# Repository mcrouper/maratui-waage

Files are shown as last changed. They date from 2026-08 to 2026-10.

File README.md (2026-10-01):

<p align="center">
    MaraTUI — rat barista
    <br><br>
    <a href="https://github.com/ratatui/ratatui">
        
    </a>
</p>

# MaraTUI

An embedded Rust TUI application for the **Lelit Mara X** espresso machine. Runs on an **ESP32** microcontroller driving an **ILI9341 320×240 display** over SPI, reads machine telemetry over UART, and publishes events to MQTT. Includes a host simulator mode for UI development without any hardware.

## Screenshots

| Loading | Dashboard | Debug |
|---|---|---|
| Loading | Dashboard | Debug |

## Screens

Navigation cycles between two main screens with a button press. The Debug screen is a hidden overlay.

### Dashboard

The primary screen. Shows all real-time machine data:

- **Mode banner** — COFFEE / STEAM / OFFLINE, color-coded
- **Boiler gauge** — current vs. target temperature with warm→ready color zones and a target marker
- **HX column** — heat-exchanger temperature with a vertical mini-gauge; ideal zone (90–95°C) is always visible
- **HEAT / PUMP indicators** — live status dots
- **Extraction timer** — large countdown in seconds, color shifts white→green→yellow as the shot progresses
- **Weight** — live shot weight in grams from the dual-HX711 scale, auto-tared the moment the pump starts
- **Shot gauge ("%")** — tracks extracted weight against a 40g target, not elapsed time
- **Shot quality label** — post-extraction assessment (UNDEREXTRACTED / GOOD / PERFECT / LONG SHOT / BLONDING) shown after the pump stops
- **Cup counter** — total shots brewed, received via MQTT

### Graphs

Temperature history chart over a **5-minute rolling window** sampled at 1 Hz:

- Boiler current temperature (yellow)
- Boiler target temperature (red)
- HX temperature (blue)

### Debug (hidden overlay)

Accessible via long press. Shows Wi-Fi and MQTT connection statuses, device info (SSID, RSSI, IP, uptime, free heap), live raw UART frame with activity indicator, and the last 10 telemetry events.

## Getting Started

### Simulator

The simulator runs on your host machine using SDL2 for display emulation — no ESP32 needed.

**Prerequisites:** install SDL2 development libraries for your OS ([installation guide](https://docs.rs/crate/sdl2/latest/source/README.md)).

```bash
make sim          # auto-detects OS
```

Or use platform-specific cargo aliases:

| OS | Command |
|---|---|
| Linux | `cargo sim` |
| macOS | `cargo simmac` |
| Windows | `cargo simwin` |

**Keyboard controls:**

| Key | Action |
|---|---|
| Right / Left | Toggle Dashboard ↔ Graphs |
| D | Toggle Debug overlay |
| Up | Inject pump-on debug frame |
| Down | Inject normal debug frame |
| Space | Inject no-water debug frame |
| M | Publish manual MQTT event |

### Device (ESP32)

**Prerequisites:** Rust with the `esp` toolchain channel (pinned in `rust-toolchain.toml`).

```bash
cargo run --release
```

Uses `espflash flash --monitor` as the runner. On startup the firmware:

1. Connects to Wi-Fi using embedded credentials
2. Starts the MQTT client and subscribes to `<prefix>/cup_counter`
3. Streams telemetry to `<prefix>/telemetry` (~1 Hz)
4. Publishes events (shot start/end, water refill, mode change) to `<prefix>/events`
5. Publishes device status (IP, RSSI, uptime, heap) to `<prefix>/status`

## Configuration

Copy `.env.example` to `.env` (git-ignored) and fill in your values:

```bash
cp .env.example .env
```

| Variable | Description |
|---|---|
| `MARATUI_WIFI_SSID` / `_PASSWORD` | Wi-Fi credentials (device build only) |
| `MARATUI_MQTT_ENABLED` | Set `true` to enable MQTT publishing |
| `MARATUI_MQTT_URL` | Broker URL, e.g. `mqtt://192.168.1.x:1883` |
| `MARATUI_MQTT_CLIENT_ID` | Unique client identifier |
| `MARATUI_MQTT_TOPIC_PREFIX` | Topic namespace prefix (default: `mara`) |

> [!NOTE]
> On the ESP32 build (`device` feature), `.env` is parsed by `build.rs` and values are embedded at compile time. On the simulator (`simulator` feature), env values are read at runtime and Wi-Fi is skipped — host networking is used directly for MQTT.

> [!WARNING]
> Wi-Fi and MQTT credentials are stored as plaintext `&'static str` in the flash image. Rotate credentials if the device is shared or its firmware is distributed. See the [Security Considerations](#security-considerations) section below.

## Home Assistant Integration

Build with `--features home-assistant` to enable MQTT Discovery publishing directly from the firmware — no Node-RED or other bridge required. On every MQTT connect, retained discovery configs are published and entities appear in Home Assistant automatically.

```bash
cargo run --release --features home-assistant   # flash
make sim-ha                                      # simulator
```

See [docs/home-assistant.md](docs/home-assistant.md) for the full entity list, MQTT topic reference, and cup counter setup.

## Web Dashboard

A standalone live dashboard page (temperatures with history, live scale weight, shot timer and weight curve, recent shots, events, device status) served by Node-RED at `http://<node-red-host>:1880/mara`, deployed with `python3 dashboard/deploy.py`. See [dashboard/README.md](dashboard/README.md).

## Hardware

Target board: **ESP32 Type-C** with an external **ILI9341** 240×320 TFT display connected over SPI. There is a single physical button.

| Press | Action |
|---|---|
| Short | Toggle Dashboard ↔ Graphs |
| Short (on loading)| Toggle display backlight |
| Double (fast 2x)  | Zero the scale |
| Long | Enter / exit Debug overlay |
| Hold (3s) | Start the scale calibration wizard |

See [`hardware/`](hardware/) for the KiCad project, PCB renders, Gerber files, and full ESP32 pinout and display wiring.

### Scale (dual HX711 load cells)

Two independent HX711 amplifiers — one per drip-tray side — feed the live Weight display and
the weight-based shot gauge. Hold the button for 3s to run the calibration wizard (tare, then a
known reference weight, for each cell in turn); results persist to NVS. The scale also auto-tares
at boot and at the start of every shot; a fast double press zeroes it manually at any time. See
[`docs/hardware.md`](docs/hardware.md) for wiring and the full calibration walkthrough.

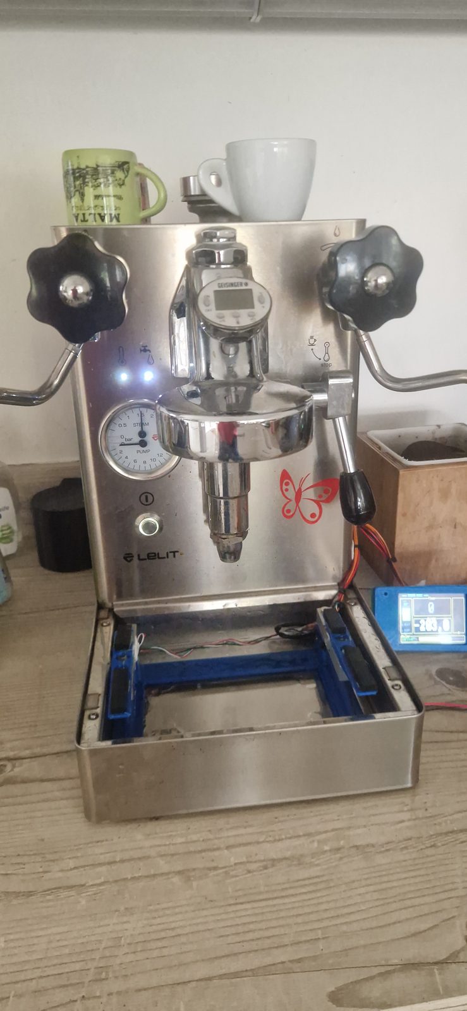
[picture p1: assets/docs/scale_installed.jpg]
Scale installed in the machine
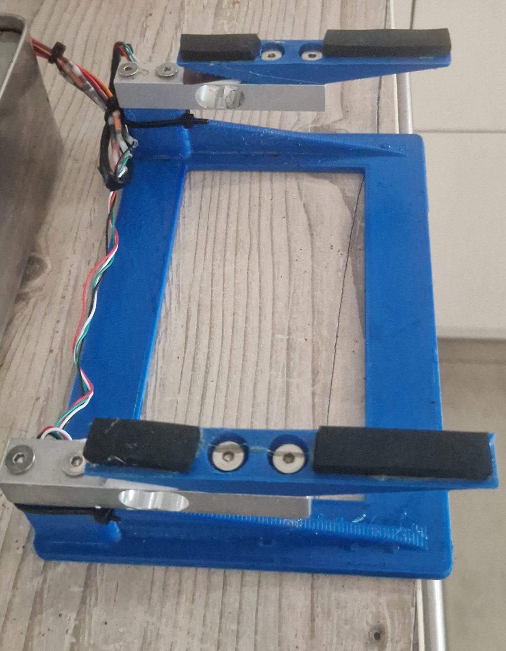
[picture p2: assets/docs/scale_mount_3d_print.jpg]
3D-printed scale mount with both load cells
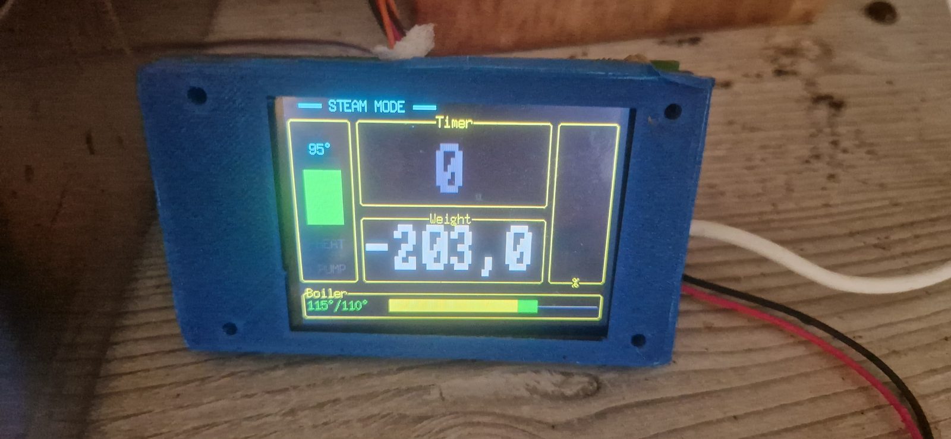
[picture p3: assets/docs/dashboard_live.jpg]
Dashboard showing a live weight reading
|  |  |  |
|:---:|:---:|:---:|

## Security Considerations

- **Credentials in flash** — Wi-Fi and MQTT credentials are embedded at compile time and extractable from the flash image with standard tools (`strings`, `binwalk`). Rotate if the device is shared.
- **Default broker is public** — `mqtt://broker.emqx.io:1883` is a free public broker with no access control. Set a private broker with authentication before deploying.
- **No TLS** — traffic is plaintext TCP. Switch to `mqtts://` and configure a CA certificate for production use.
- **Open Wi-Fi fallback** — if `MARATUI_WIFI_PASSWORD` is empty, `AuthMethod::None` is used (no encryption). A startup `warn!` names the SSID to make this explicit.

## Roadmap

- Offline mode using NVS storage

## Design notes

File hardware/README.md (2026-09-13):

# MaraTUI PCB

Custom ESP32 controller board for the [Lelit Mara X](https://lelitcoffee.com/product/mara-x/) espresso machine.

## PCB Render

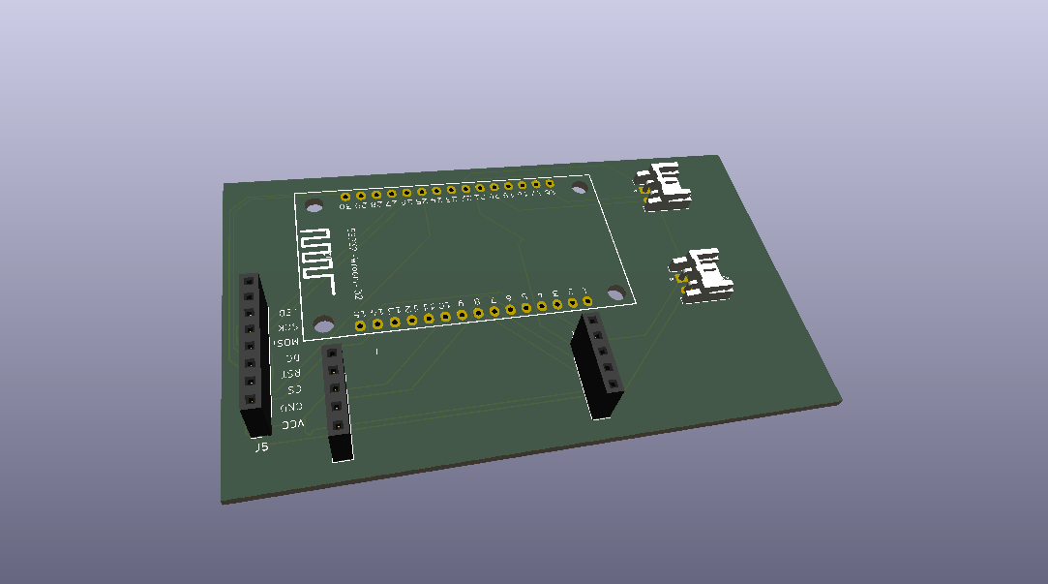
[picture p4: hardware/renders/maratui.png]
PCB render


## Components

| Ref | Part | Link |
|-----|---|---|
| U1 | ILI9341 2.8" SPI TFT with touch | [Amazon TR](https://www.amazon.com.tr/2-8in%C3%A7-SPI-Dokunmatik-Ekran-Mod%C3%BCl%C3%BC/dp/B0GWFFJBZN) |
| U2 | ESP32-WROOM-32 | [Amazon TR](https://www.amazon.com.tr/ESP32-Wroom-32-Wifi-Bluetooth-Geli%C5%9Ftirme-Kart%C4%B1/dp/B0BT7SW1LF) |
| SW1 | Tactile switch | |
| J1 | Barrel jack (power) | |
| J2 | 3-pin connector (GND + UART) | |
| U3, U4 | HX711 load-cell amplifier (one per scale cell) | |

## Wiring

### SPI Display (ILI9341)

| Display Pin | ESP32 GPIO | Notes |
|---|---|---|
| SCK / CLK | GPIO18 | VSPI CLK |
| SDA / MOSI  | GPIO21 | VSPI MOSI |
| DC / RS | GPIO23 | Data/Command select |
| CS | GPIO19 | Chip Select |
| RST / RESET | GPIO22 | Hardware reset |
| LED / BLK | GPIO14 | Backlight (HIGH = on) |
| VCC | 3.3V | |
| GND | GND | |

### UART (Lelit Mara X telemetry)

| Function | ESP32 GPIO | Notes |
|---|---|---|
| TX | GPIO17 | UART1 TX |
| RX | GPIO16 | UART1 RX |

### Scale (dual HX711 load cells)

| HX711 Pin | ESP32 GPIO | Notes |
|---|---|---|
| DOUT (left)  | GPIO25 | Data, left load cell (input on ESP32) |
| SCK (left) | GPIO26 | Clock, left load cell (output from ESP32) |
| DOUT (right) | GPIO32 | Data, right load cell (input on ESP32) |
| SCK (right)  | GPIO27 | Clock, right load cell (output from ESP32) |

Each HX711 has its **own** DOUT and SCK line (not shared) so the two cells can be clocked and
read independently — one under each side of the drip tray. See
[`docs/hardware.md`](../docs/hardware.md) for E+/E-/A+/A- load-cell wiring and the calibration
procedure.

### Button

| Button | ESP32 GPIO | Notes |
|---|---|---|
| SW1 | GPIO12 | Internal pull-up enabled |

Button connects GPIO to **GND** via a tactile switch (active LOW, falling-edge detection).

- Short press (< 500 ms): cycle screens (Dashboard ↔ Graphs)
- Double press (two short presses within 400 ms): zero the scale
- Long press (≥ 500 ms): toggle Debug screen
- Hold (3 s): start the scale calibration wizard

## Custom Libraries

Non-standard components are bundled in `lib/` so the project opens without missing library errors on any machine.

| File | Description |
|---|---|
| `lib/symbols/esp32_30pin.kicad_sym` | ESP32-WROOM-32 symbol |
| `lib/symbols/tft_320x240.kicad_sym` | ILI9341 320×240 symbol |
| `lib/footprints/maratui.pretty/ESP32_30pin.kicad_mod` | ESP32 footprint |
| `lib/footprints/maratui.pretty/TFT-320x240.kicad_mod` | TFT display footprint |

## Manufacturing

Gerber files for fabrication: `gerbers/gerbers.zip` (single board, scale cells included)

## 3D-Printed Parts (`3d-print/`)

Printable case parts for the dual load-cell scale mount:

| File | Description |
|---|---|
| `doppelfuss.stp` / `ImageToStl.com_doppelfuss.stl` | Double foot — mounts both load cells |
| `auflage_v2.stp` / `ImageToStl.com_auflage_v2.stl` | Scale platform/tray (v2) |
| `CCR10S_ImageToStl.com_auflage_v2.gcode` | Pre-sliced G-code for the platform (Creality CR-10S) |

Tested with JLCPCB default 2-layer settings.

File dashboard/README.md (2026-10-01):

# Web dashboard

A standalone live dashboard page for MaraTUI, served by Node-RED at `http://<node-red-host>:1880/mara`:
boiler / HX temperatures with history, heating / pump / water / boost state, live scale weight,
shot timer, shot weight curve, recent shots (duration, yield, flow), event log and device status.
No external dependencies (no CDN, no Dashboard nodes) — it works on an offline LAN.

## How it works

```
mqtt in (mara/#) → function "Zustand + Broadcast" → websocket out /ws/mara  (broadcast to all pages)
websocket in /ws/mara → function "Snapshot an neuen Client" → websocket out  (state for a new page)
http in GET /mara → template (index.html) → http response
http in GET /mara/shot/:ts → function → http response            (the shot's JPEG, linked in the table)
```

Node-RED keeps the state (last hour of temperatures, last 10 shots, last 30 events) in flow
context, so a freshly opened page is populated immediately; the browser never talks to the MQTT
broker itself, so no broker credentials end up in the page.

Shots survive Node-RED restarts and power cuts: the function node writes them to `$HOME/maratui/`
of the Node-RED user (`--data-dir` to change) and reloads them on start:

- `shots.json` — the last 10 shots incl. weight and HX curves (written atomically with fsync)
- `shotdoku.txt` — plain-text archive; every shot pushed out of the last 10 is appended, e.g.
  `2026-09-27 14:39:28  Dauer 11 s  Gewicht 41,9 g  Fluss 3,8 g/s  HX 95-104 °C  (kurz)` plus a
  weight-per-second line

- `shots/JJJJ-MM-TT_HH-MM-SS.jpg` — one chart per shot (weight curve, HX temperature behind it,
  duration / weight / flow in the title), rendered on the Node-RED host by `render_shot.py`
  (needs `python3` with Pillow and the DejaVu fonts, both on Raspberry Pi OS by default). The
  flow installs the script into the data dir on start and renders missing images for saved shots.
- `cups.json` — total cup count, +1 for every shot that enters the shot list (normal shots and
  short pours with >= 5 g, not rinses). Published retained to `mara/cup_counter`, so the ESP32
  display shows it too — this replaces the Home Assistant automation for setups without HA. To set
  a start value: `mosquitto_pub -r -t mara/cup_counter -m 1234` (plus `-h/-u/-P`); the flow adopts it.

Temperature history and events stay in memory only.

`reducer.js` is the single implementation of how MQTT messages update that state. `deploy.py`
injects it both into the Node-RED function node and into the page, so server and browser can't
drift apart.

## Deploy / update

```bash
python3 dashboard/deploy.py                      # default: http://192.168.178.162:1880
python3 dashboard/deploy.py --url http://host:1880 --broker <mqtt-broker config node id>
python3 dashboard/deploy.py --dry-run            # print the generated flow JSON
```

Creates the Node-RED tab **MaraTUI Web** on first run and updates it in place afterwards (stable
node ids); other flows are left untouched. It subscribes through the existing mqtt-broker config
node named `MaraTUI Broker` unless `--broker` is given. Edit the files here and redeploy rather than
editing the generated nodes in the Node-RED editor.

Requires the Node-RED admin API to be reachable without auth (or add auth handling to `deploy.py`).

## Topics used

`mara/telemetry`, `mara/status`, `mara/events` (incl. `weight_g` on `shot_ended`), `mara/scale`,
`mara/cup_counter` — see [docs/home-assistant.md](../docs/home-assistant.md#mqtt-topics-published-by-maratui).
The `mara` prefix is hardcoded in `deploy.py` (`TOPIC`); change it there if
`MARATUI_MQTT_TOPIC_PREFIX` differs.

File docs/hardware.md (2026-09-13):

# Hardware Wiring

Target board: **ESP32 Type-C** (generic) with external **ILI9341** 240x320 TFT display.

| ESP32 Type-C | ILI9341 Display |
|:---:|:---:|
| ESP32 | ILI9341 |

## Complete Pin Mapping

Tested board: **ESP32 DevKitV1** (30-pin WROOM-32 "DOIT DEVKIT V1" layout). The
`D<n>` column is that board's silkscreen label, which is just `GPIO<n>` — use whichever
matches your board.

| ESP32 GPIO | DevKitV1 label | Function | Direction | Notes |
|---|---|---|---|---|
| GPIO12 | D12  | Button 1 | Input | Internal pull-up, active LOW. Boot-strapping pin (sets flash voltage); safe here since the button only pulls it LOW, and the internal pull-up is applied by software after boot, not during strapping. |
| GPIO14 | D14  | Display backlight | Output | HIGH = on |
| GPIO16 | D16 (silkscreen "RX2") | UART1 RX | Input | Lelit Mara X telemetry. "RX2" label is just a UART2 suggestion — used here as plain GPIO for UART1 |
| GPIO17 | D17 (silkscreen "TX2") | UART1 TX | Output | Lelit Mara X telemetry (unused by device, wired for symmetry) |
| GPIO18 | D18  | Display SCK / CLK | Output | VSPI CLK |
| GPIO19 | D19  | Display CS | Output | VSPI Chip Select |
| GPIO21 | D21  | Display SDA / MOSI | Output | VSPI MOSI |
| GPIO22 | D22  | Display RST | Output  | Hardware reset |
| GPIO23 | D23  | Display DC / RS | Output | Data/Command select |
| GPIO25 | D25  | HX711 DOUT (left)  | Input  | Left load cell |
| GPIO26 | D26  | HX711 SCK (left) | Output | Left load cell |
| GPIO27 | D27  | HX711 SCK (right)  | Output | Right load cell |
| GPIO32 | D32  | HX711 DOUT (right) | Input  | Right load cell |

Details for each subsystem below.

## Pinout

### SPI Display (ILI9341)

| Display Pin | ESP32 GPIO | Notes |
|---|---|---|
| SCK / CLK | GPIO18 | VSPI CLK |
| SDA / MOSI  | GPIO21 | VSPI MOSI |
| DC / RS | GPIO23 | Data/Command select |
| CS | GPIO19 | Chip Select |
| RST / RESET | GPIO22 | Hardware reset |
| LED / BLK | GPIO14 | Backlight (driven HIGH = on) |
| VCC | 3.3V | |
| GND | GND | |

### UART (Lelit Mara X telemetry)

| Function | ESP32 GPIO | Notes |
|---|---|---|
| TX | GPIO17 | UART1 TX |
| RX | GPIO16 | UART1 RX |

### Button

| Button | ESP32 GPIO | Notes |
|---|---|---|
| Button 1 | GPIO12 | Internal pull-up enabled |

Button connects GPIO to **GND** through a tactile switch (active LOW, NegEdge detection).
Short press (< 500 ms): toggle Dashboard ↔ Graphs. Two short presses released within 400 ms
of each other count as a double press instead: zero the scale (see below). Because a lone
short press can't be told apart from the first half of a double press until that 400 ms
window has passed without a second press, every short-press action (screen toggle, backlight
wake) fires up to ~400 ms after release, not instantly. Long press (≥ 500 ms, < 3 s): toggle
Debug screen. Hold ≥ 3 s: start the scale calibration wizard (see below).

### Scale (dual HX711 load-cell amplifiers)

The scale uses **two independent HX711 amplifiers**, each wired to its own load cell
(e.g. one under each side of the drip tray) with its own DOUT *and* SCK line — the two
ADCs are clocked separately rather than sharing one clock. Their raw readings are
calibrated independently and summed into the total weight shown on the Dashboard.

| HX711 Pin | ESP32 GPIO | Notes |
|---|---|---|
| DOUT (left)  | GPIO25 | Data, left load cell (input on ESP32) |
| SCK (left) | GPIO26 | Clock, left load cell (output from ESP32) |
| DOUT (right) | GPIO32 | Data, right load cell (input on ESP32) |
| SCK (right)  | GPIO27 | Clock, right load cell (output from ESP32) |
| VCC (both) | 3.3V / 5V  | Per HX711 board spec |
| GND (both) | GND | |

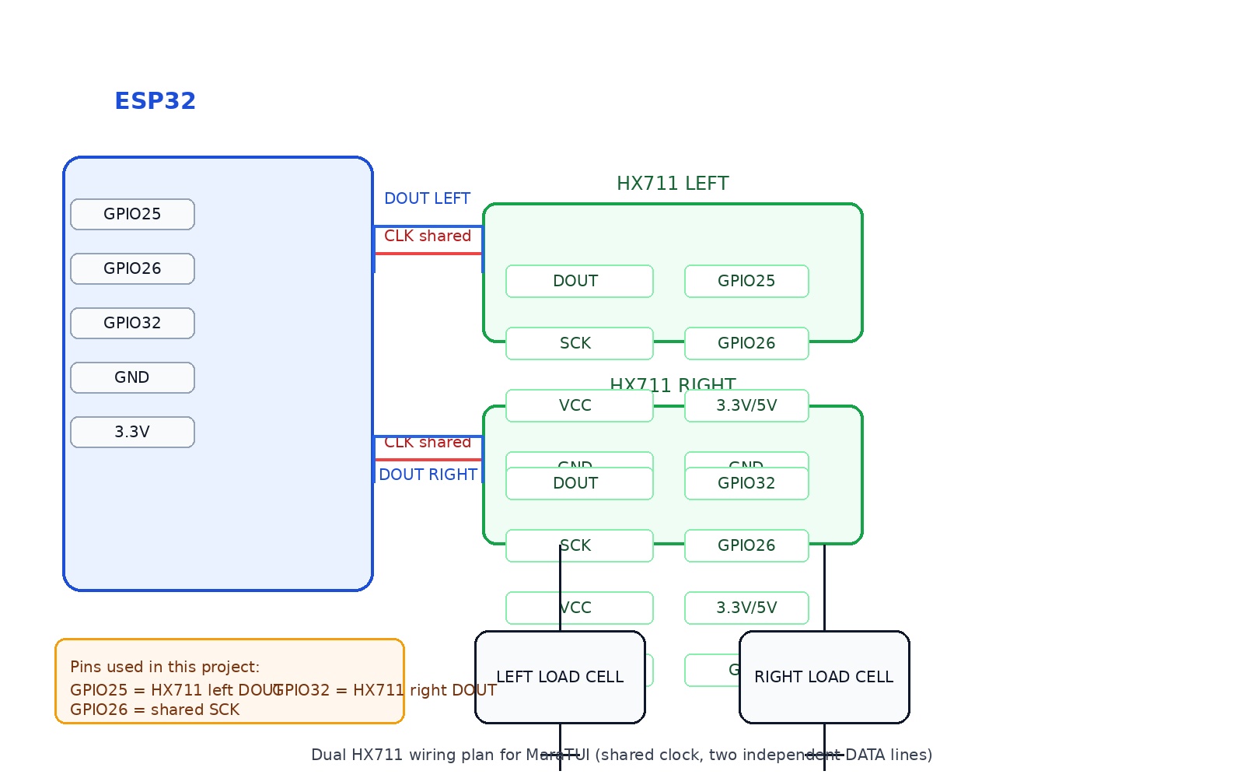
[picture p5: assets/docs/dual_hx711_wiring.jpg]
Dual HX711 wiring
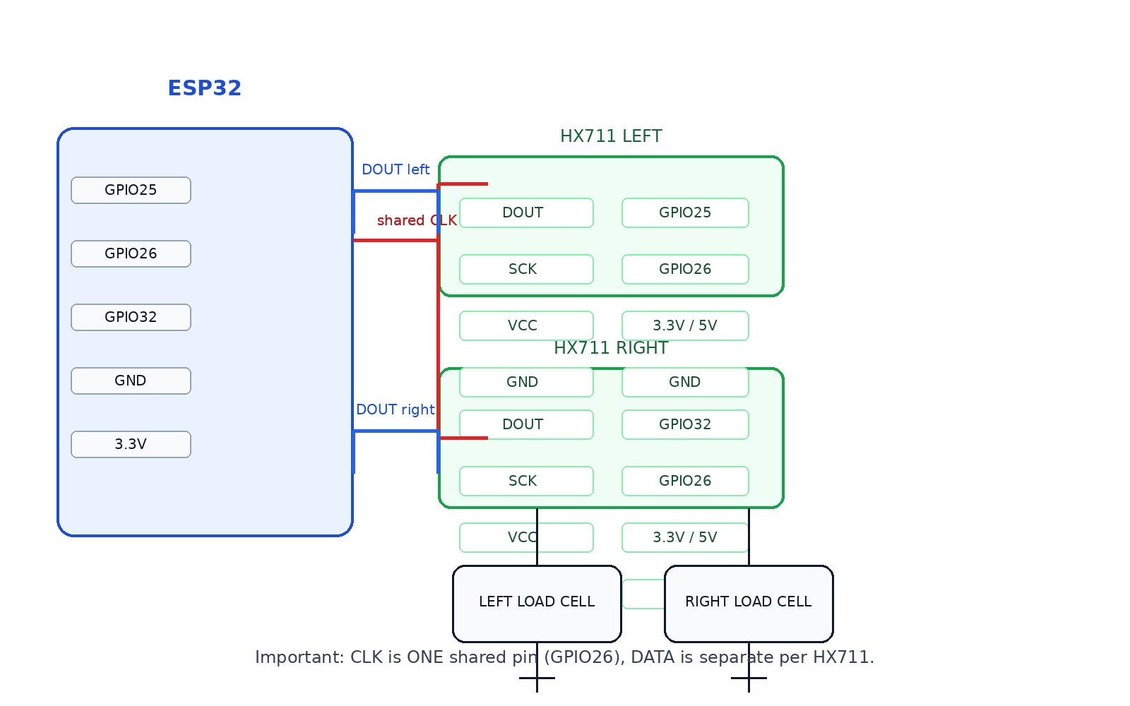
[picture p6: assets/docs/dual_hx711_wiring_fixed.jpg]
Dual HX711 wiring, corrected
|  |  |
|:---:|:---:|

Each load cell connects to its own HX711 board's E+/E-/A+/A- terminals per the load
cell's datasheet. Both drivers read channel A at gain 128 (the HX711 default).

#### Calibrating the scale

Calibration data (per-cell zero-point offset + counts-per-gram factor) is stored in NVS
flash and survives reboots. The wizard calibrates the **left cell first, then the right
cell**, each with its own zero + reference step. To (re-)calibrate:

1. Hold **Button 1** for 3 seconds to enter the calibration wizard.
2. **Left cell — zero point:** remove everything from the scale, then short-press Button 1
   to confirm. The device tares the left HX711 (averages ~10 raw samples as the
   zero-point).
3. **Left cell — reference weight:** place a **500 g** reference weight on the scale, then
   short-press Button 1 to confirm. The device computes the left cell's counts-per-gram
   scale factor from this reading.
4. **Right cell — zero point / reference weight:** repeat steps 2–3 for the right cell.
5. A result screen confirms success for both cells (or reports a read failure — check
   wiring and retry). Press either button to dismiss and return to the previous screen.

A long press at any step during the wizard cancels without changing the stored
calibration. The Dashboard shows live weight (left + right combined) once calibrated; it
auto-tares both cells the moment a shot starts, so it displays the net extracted weight. It
also auto-tares once on the very first reading after boot, and a fast double press zeroes it
manually at any time (ignored while the calibration wizard itself is active).

Before the wizard has ever been run (nothing saved to NVS yet), the scale is uncalibrated
(`ScaleCalibration::default()`, `scale = 0.0`) and readings are rejected outright — the
Dashboard shows `--` until calibration completes.

#### Finished build

The scale mount installed in the Mara X's drip tray, and the Dashboard showing a live weight
reading:

| Scale installed in the machine | 3D-printed scale mount with both load cells | Dashboard showing a live weight reading |
|:---:|:---:|:---:|

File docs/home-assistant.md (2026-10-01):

# Home Assistant Integration

MaraTUI can publish Home Assistant MQTT Discovery configs directly from the firmware — no Node-RED or any other bridge required.

## Architecture

```
ESP32 (MaraTUI)
    │  UART telemetry
    │  MQTT (homeassistant/# discovery + state)
    └─► MQTT broker ──────────────────────────────► Home Assistant
                                                          │
                                                    sensors / binary sensors
                                                    auto-registered via Discovery
```

On connect, the firmware publishes retained discovery configs to `homeassistant/sensor/maratui_*/config` and `homeassistant/binary_sensor/maratui_*/config`. Home Assistant picks them up automatically — no manual YAML needed.

## Prerequisites

- MQTT broker reachable by both the ESP32 and Home Assistant (e.g. Mosquitto on the same host)
- Home Assistant with the MQTT integration enabled (Settings → Devices & Services → MQTT)

## Enabling HA Discovery

Add `--features home-assistant` to your build command:

**Flash to device:**
```bash
cargo run --release --features home-assistant
# or
make flash-ha
```

**Run the simulator:**
```bash
cargo simha          # Linux
cargo simmacHA       # macOS
make sim-ha          # auto-detects OS
```

That's it — on first MQTT connect the firmware publishes all discovery configs, and entities appear in HA within seconds.

## MQTT Topics Published by MaraTUI

### `<prefix>/telemetry` — ~1 Hz JSON frame

```json
{
  "mode": "Coffee",
  "sw": "1.10",
  "boiler_now_c": 93,
  "boiler_target_c": 94,
  "hx_now_c": 91,
  "boost_countdown_s": 0,
  "heating_on": false,
  "pump_on": false,
  "no_water_code": null
}
```

### `<prefix>/events` — on-change JSON events

| `type` | Extra fields | Description |
|---|---|---|
| `shot_started` | — | Pump just turned on |
| `shot_ended` | `duration` (int, seconds), `weight_g` (number or `null`) | Pump turned off; duration and yield (net scale weight, tared at shot start; `null` without a scale reading) |
| `shot_aborted` | `duration` (int, seconds), `weight_g` (number or `null`) | Pump ran < 15 s (rinse / pre-heat kick, or a very short pour) |
| `water_refill_needed` | `code` (int) | Water low detected |
| `water_refill_cleared` | — | Water low cleared |
| `mode_changed` | `from`, `to` (strings) | Machine mode transition |

### `<prefix>/scale` — scale weight, on change (≤ 4 Hz)

```json
{ "weight_g": 36.2 }
```

Net weight shown on the display (grams, one decimal): tared on boot, at every shot start and on a
double press. Published only when the value changes, at most every 250 ms.

### `<prefix>/status` — periodic device info (~30 s)

```json
{
  "uptime_s": 3600,
  "wifi_ssid": "MyNetwork",
  "wifi_rssi": -62,
  "ip": "192.168.1.42",
  "free_heap_b": 180000,
  "last_telemetry_age_s": 1
}
```

The topic prefix defaults to `mara` and is configured via `MARATUI_MQTT_TOPIC_PREFIX` in `.env`.

## Home Assistant Entities

All entities appear under a single device named **Lelit Mara X**.

### Sensors

| Entity | Unit | Notes |
|---|---|---|
| Mode | — | Operating mode |
| Firmware Version | — | Diagnostic |
| Boiler Temperature | °C | `device_class: temperature` |
| Boiler Target | °C | `device_class: temperature` |
| HX Temperature | °C | `device_class: temperature` |
| Last Extraction Duration | s | Retained; updated on shot end |
| Extraction Timer | s | Live counter during shot |
| Time Since Last Shot | min | Minutes since pump last stopped |
| Cup Counter | — | See cup counter setup below |
| Uptime | min | Diagnostic |
| Wi-Fi RSSI | dBm | Diagnostic |
| Wi-Fi SSID | — | Diagnostic |
| IP Address | — | Diagnostic |
| Free Heap | kB | Diagnostic |
| Telemetry Age | s | Diagnostic |

### Binary Sensors

| Entity | Notes |
|---|---|
| Heating | `device_class: heat` |
| Pump Active | On while shot is in progress |
| Water Level Low | `device_class: problem` |

## Cup Counter Setup

The cup counter requires a short one-time setup in Home Assistant. The counter value is stored as an HA helper and published back to the broker so the MaraTUI display stays in sync.

### 1. Create a Counter helper

Settings → Devices & Services → Helpers → **+ Create helper** → **Counter**

- Name: `Mara Shots`
- Entity ID: `counter.coffee_counter` (default)
- Initial value: your current count (or 0)

### 2. Import the automation

Settings → Automations → **+ Create automation** → ⋮ menu → **Edit in YAML**

Paste the contents of `docs/ha-automation.yaml`, save, and enable.

The automation triggers on `mara/events` when `type == shot_ended` and `duration > 20 s`, increments the helper, and publishes the new value to `mara/cup_counter` (retained) so both the HA sensor and the ESP32 display update.

### Cup counter flow

```
MaraTUI → mara/events {"type":"shot_ended","duration":35}
               ↓
         HA automation (ha-automation.yaml)
         duration > 20 s → counter.increment(counter.coffee_counter)
                         → mqtt.publish(mara/cup_counter, retained)
               ↓
         ESP32 subscribes to mara/cup_counter → display updates
         HA sensor maratui_cup_counter reads mara/cup_counter → HA updates
```

## Troubleshooting

**Entities don't appear in HA**
- Check that the MQTT integration is enabled (Settings → Devices & Services → MQTT).
- Confirm the broker MaraTUI connects to is the same one HA uses.
- Subscribe to `homeassistant/#` with `mosquitto_sub -t 'homeassistant/#' -v` to verify discovery configs are arriving.
- Power-cycle or reconnect the ESP32 — discovery configs are re-sent on every MQTT connect.

**Values don't update**
- Confirm the ESP32 is connected to Wi-Fi and MQTT (`MARATUI_MQTT_ENABLED=true` in `.env`).
- Check the MaraTUI Debug screen for UART activity and connection status.
- Subscribe to `mara/#` to see raw messages from the device.

**Topic mismatch**
- If you set `MARATUI_MQTT_TOPIC_PREFIX` to something other than `mara`, update the topics in `docs/ha-automation.yaml` accordingly.

**Cup counter not incrementing**
- Verify the automation is enabled and the trigger topic matches your prefix.
- Check HA automation traces (Settings → Automations → Mara Shot Counter → ⋮ → Traces).

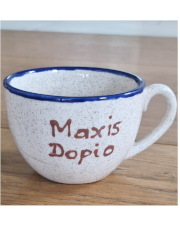
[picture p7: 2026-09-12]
assets/rat_barista.png

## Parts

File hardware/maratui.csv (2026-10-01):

ID | Bezeichner | Footprint | Stückzahl | Bezeichnung | Anbieter und Referenz
1 | J2 | JST_EH_B2B-EH-A_1x02_P2.50mm_Vertical | 1 | Button
2 | J4 | JST_EH_B2B-EH-A_1x02_P2.50mm_Vertical | 1 | Mara
3 | U1 | ESP32_30pin | 1 | ~
4 | U2, U3 | HX711_module | 2 | HX711
5 | U4 | TFT-320x240 | 1 | TFT_320x240

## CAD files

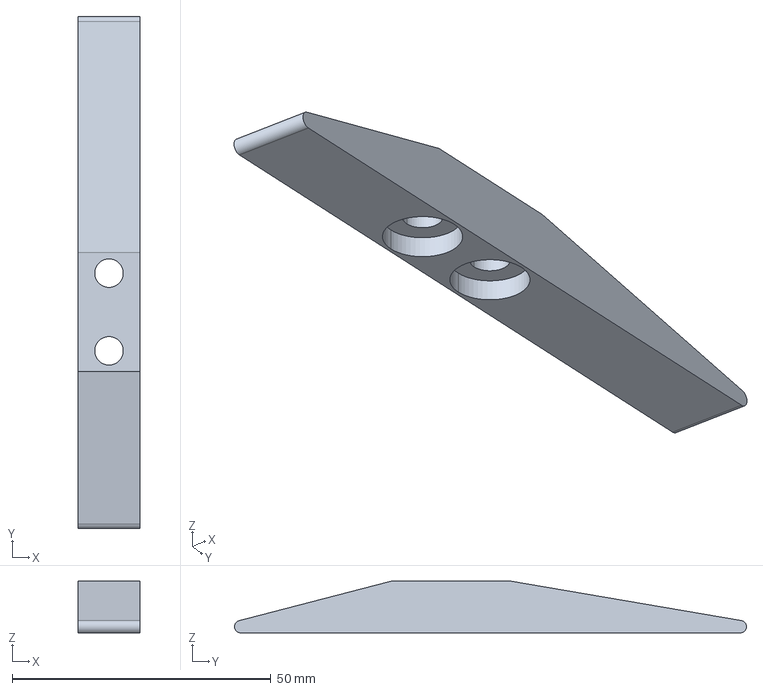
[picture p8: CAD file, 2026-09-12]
hardware/3d-print/auflage_v2.stp
12.0 x 98.9 x 10.0 mm

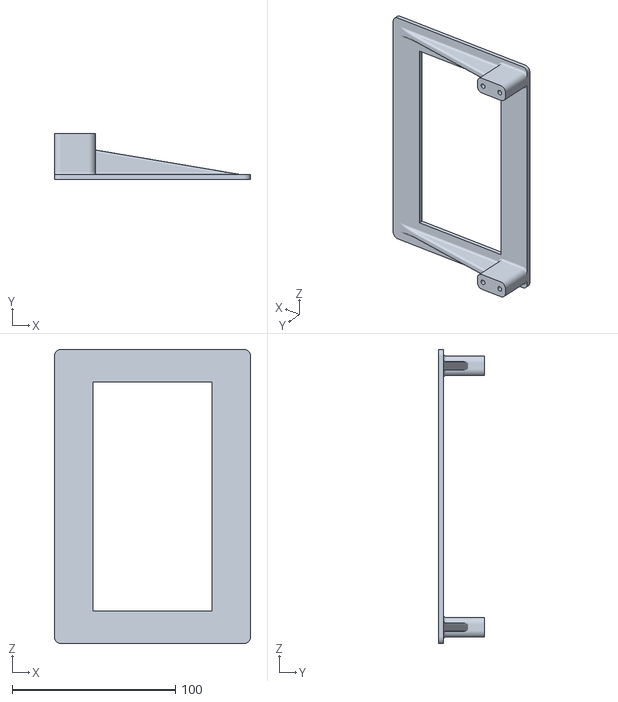
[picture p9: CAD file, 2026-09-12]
hardware/3d-print/ImageToStl.com_doppelfuss.stl
120.0 x 28.0 x 180.0

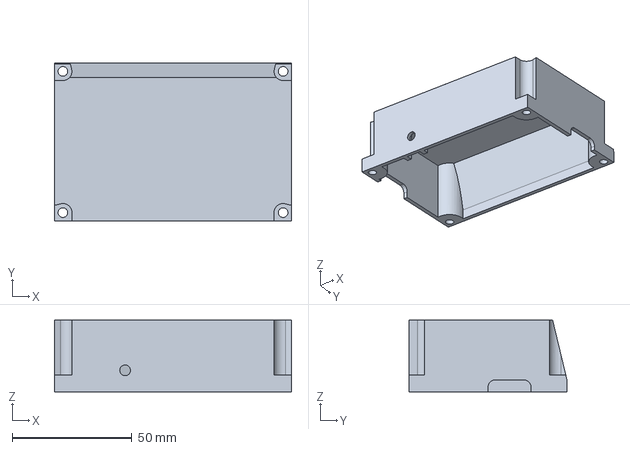
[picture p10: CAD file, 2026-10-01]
hardware/3d-print/00000000000_-_geh_koerper.stp
99.0 x 66.0 x 30.0 mm

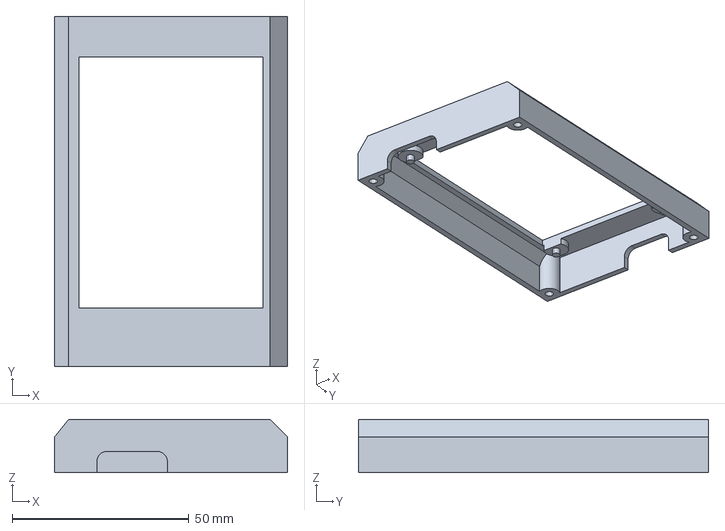
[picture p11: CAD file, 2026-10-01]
hardware/3d-print/00000000000_-_geh_deckel.stp
66.0 x 99.0 x 15.0 mm

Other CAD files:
hardware/3d-print/ImageToStl.com_auflage_v2.stl
hardware/3d-print/doppelfuss.stp

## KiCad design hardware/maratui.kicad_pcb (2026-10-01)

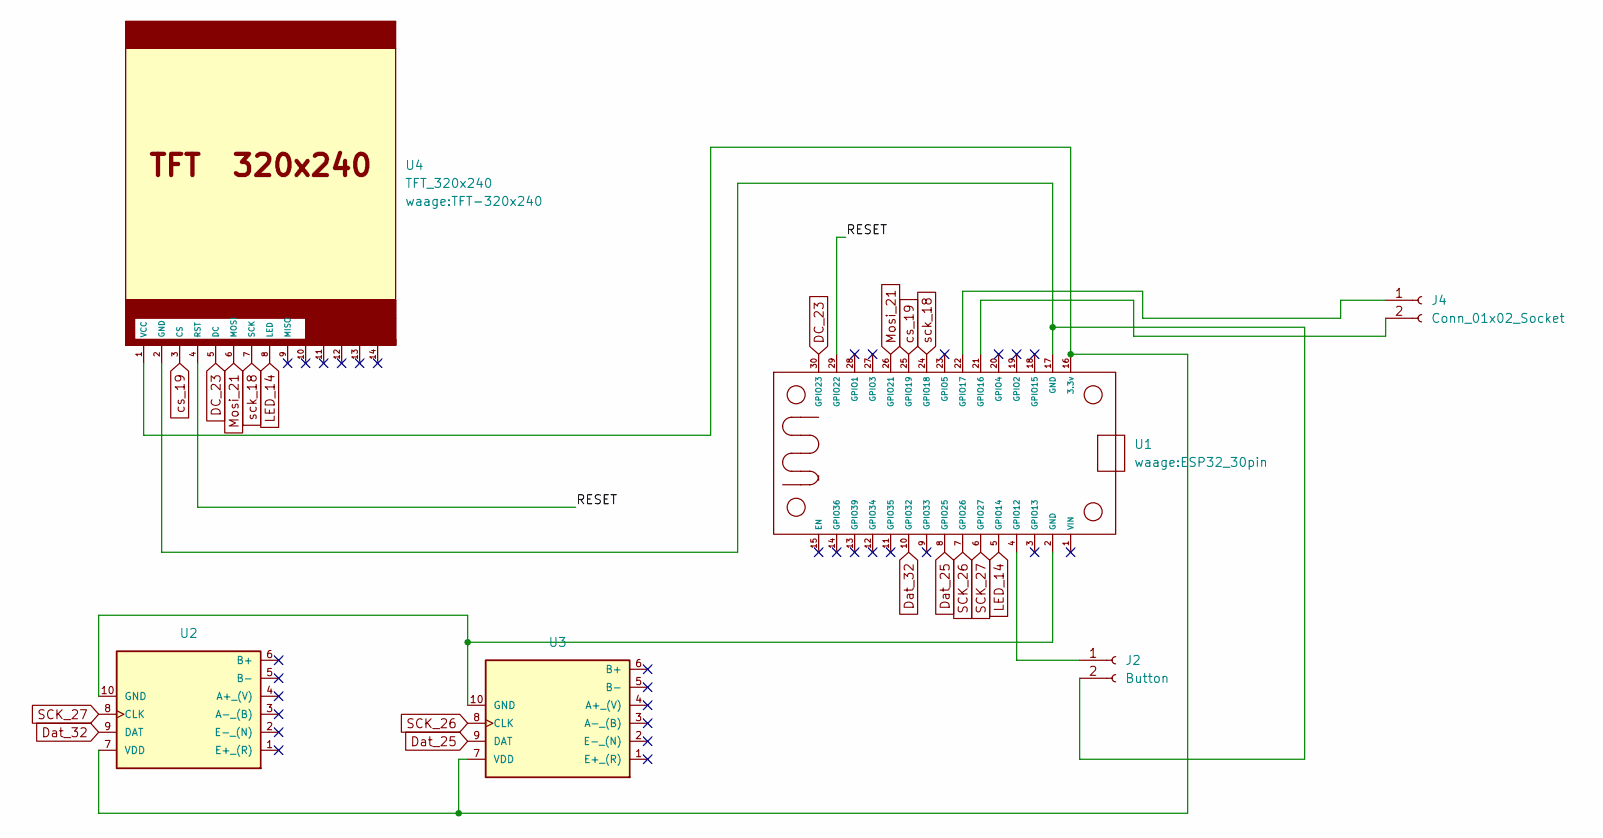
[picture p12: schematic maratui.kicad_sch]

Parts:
J2: Button; JST_EH_B2B-EH-A_1x02_P2.50mm_Vertical
J4: Conn_01x02_Socket; JST_EH_B2B-EH-A_1x02_P2.50mm_Vertical
U1: ESP32_30pin
U2, U3: HX711; HX711_module
U4: TFT_320x240; TFT-320x240

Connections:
/RESET: U1.29 (GPIO22), U4.4 (RST)
DC_23: U1.30 (GPIO23), U4.5 (DC)
Dat_25: U1.8 (GPIO25), U3.9 (DAT)
Dat_32: U1.10 (GPIO32), U2.9 (DAT)
LED_14: U1.5 (GPIO14), U4.8 (LED)
Mosi_21: U1.26 (GPIO21), U4.6 (MOSI)
unnamed: J2.1, U1.4 (GPIO12)
unnamed: J2.2, U1.17 (GND), U4.2 (GND)
unnamed: J4.1, U1.22 (GPIO17)
unnamed: J4.2, U1.21 (GPIO16)
unnamed: U1.16 (3.3v), U2.7 (VDD), U3.7 (VDD), U4.1 (VCC)
unnamed: U1.2 (GND), U2.10 (GND), U3.10 (GND)
SCK_26: U1.7 (GPIO26), U3.8 (CLK)
SCK_27: U1.6 (GPIO27), U2.8 (CLK)
cs_19: U1.25 (GPIO19), U4.3 (CS)
sck_18: U1.24 (GPIO18), U4.7 (SCK)

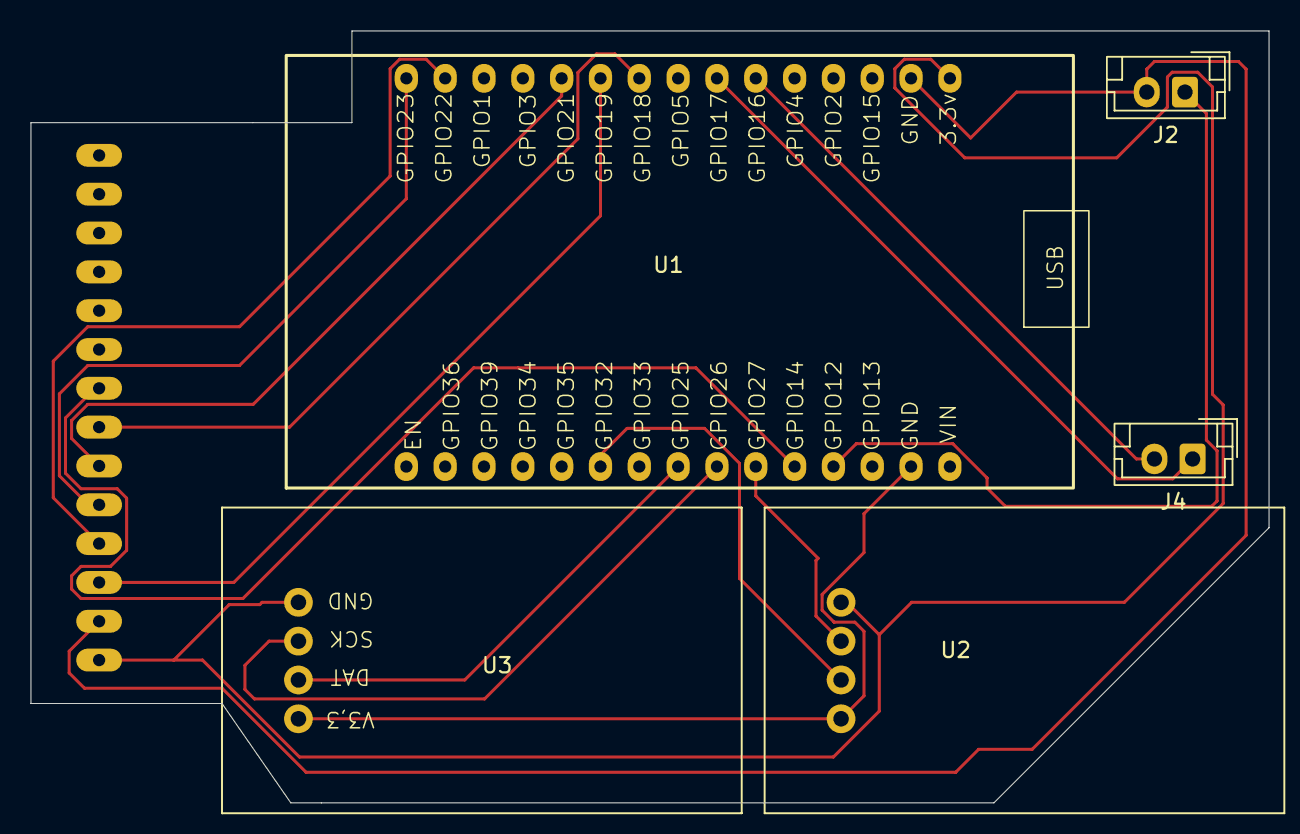
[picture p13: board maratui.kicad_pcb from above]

Board: 2 copper layers, 81.0 x 50.5 mm, 6 parts (1 on the bottom side), 16 nets.

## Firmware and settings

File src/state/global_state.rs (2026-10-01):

use crate::screens::Screen;
use crate::telemetry::MachineState;
use std::{
    collections::VecDeque,
    time::{Duration, Instant},
};

// TODO: if the device is powered directly from the espresso machine, the backlight
// timeout is unnecessary — consider removing BACKLIGHT_TIMEOUT and backlight_should_be_on entirely.
pub const BACKLIGHT_TIMEOUT: Duration = Duration::from_secs(10);

/// How long telemetry may be absent before the machine is considered offline.
///
/// Once this elapses with no UART frame, the UI falls back to the waiting screen and
/// the next frame to arrive starts a fresh session (terminal + graph buffers cleared).
pub const MACHINE_OFFLINE_TIMEOUT: Duration = Duration::from_secs(30);

#[derive(Clone, Debug, Default, PartialEq, Eq)]
pub enum ConnectionStatus {
    Disabled,
    #[default]
    Disconnected,
    Connecting,
    Connected,
    Error(String),
}

#[derive(Clone, Debug)]
pub struct MqttOutboundMessage {
    /// Topic suffix (combined with prefix by publish_mqtt_message) unless `absolute` is true.
    pub topic_suffix: String,
    pub payload: String,
    /// When `true`, the broker should store a retained copy of this message.
    pub retain: bool,
    /// When `true`, `topic_suffix` is used as-is (bypasses prefix construction).
    pub absolute: bool,
}

/// State of the coffee extraction process
#[derive(Clone, Debug, PartialEq, Eq)]
pub enum ExtractionState {
    /// Pump is not running, no extraction in progress
    Idle {
        /// Duration of the last completed extraction
        last_extraction_duration: Option<Duration>,
    },
    /// Pump is running, extraction in progress
    Extracting { started_at: Instant },
}

impl Default for ExtractionState {
    fn default() -> Self {
        Self::Idle {
            last_extraction_duration: None,
        }
    }
}

impl ExtractionState {
    /// Get the duration of the current extraction (if in progress)
    pub fn elapsed(&self) -> Option<Duration> {
        match self {
            ExtractionState::Extracting { started_at } => Some(started_at.elapsed()),
            ExtractionState::Idle { .. } => None,
        }
    }

    /// Check if extraction is currently in progress
    pub fn is_extracting(&self) -> bool {
        matches!(self, ExtractionState::Extracting { .. })
    }

    /// Get the duration of the last completed extraction
    pub fn last_extraction_duration(&self) -> Option<Duration> {
        match self {
            ExtractionState::Idle {
                last_extraction_duration,
            } => *last_extraction_duration,
            ExtractionState::Extracting { .. } => None,
        }
    }
}

/// Board metadata published to MQTT and shown on the Debug screen
#[derive(Clone, Debug, Default, PartialEq, Eq)]
pub struct DeviceInfo {
    pub wifi_ssid: String,
    pub wifi_rssi: Option<i32>,
    pub ip: Option<String>,
    pub uptime_s: u64,
    pub free_heap_b: Option<u32>,
    /// Seconds since the last UART telemetry frame was received
    pub last_telemetry_age_s: Option<u64>,
}

/// Step of the on-screen HX711 scale calibration wizard, started by holding Button1 for 3s.
#[derive(Clone, Copy, Debug, PartialEq, Eq)]
pub enum CalibrationStep {
    /// Ask the user to empty the left scale; a short press confirms and starts taring.
    ConfirmEmptyLeft,
    /// Averaging raw samples for the left scale zero-point.
    TaringLeft,
    /// Ask the user to place the reference weight on the left scale.
    ConfirmReferenceLeft,
    /// Averaging raw samples with the left scale reference weight.
    CalibratingLeft,
    /// Ask the user to empty the right scale; a short press confirms and starts taring.
    ConfirmEmptyRight,
    /// Averaging raw samples for the right scale zero-point.
    TaringRight,
    /// Ask the user to place the reference weight on the right scale.
    ConfirmReferenceRight,
    /// Averaging raw samples with the right scale reference weight.
    CalibratingRight,
    /// Final result, shown briefly before returning to the previous screen.
    Done { success: bool },
}

/// Application errors
#[derive(Clone, Debug, PartialEq, Eq)]
pub enum AppError {
    /// Water refill is needed
    WaterRefillNeeded { code: u16 },
    /// Machine is offline
    MachineOffline,
}

impl std::fmt::Display for AppError {
    fn fmt(&self, f: &mut std::fmt::Formatter<'_>) -> std::fmt::Result {
        match self {
            AppError::WaterRefillNeeded { code } => {
                write!(f, "Water refill needed (code: {})", code)
            }
            AppError::MachineOffline => write!(f, "Machine is offline"),
        }
    }
}
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

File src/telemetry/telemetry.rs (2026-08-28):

// src/telemetry.rs
use std::{collections::VecDeque, time::Instant};
use strum::Display;

#[derive(Debug, Display, Default, Clone, Copy, PartialEq, Eq)]
pub enum MachineMode {
    #[strum(to_string = "Coffee")]
    Coffee, // '-' | '+'
    #[strum(to_string = "Steam")]
    SteamS, // 'S'
    #[strum(to_string = "Steam")]
    SteamV, // 'V'
    #[strum(to_string = "Steam")]
    SteamC, // 'C' (as you described)
    #[default]
    Offline, // 'X'
    Unknown(char),
}

impl MachineMode {
    pub fn from_char(c: char) -> Self {
        match c {
            '-' | '+' => MachineMode::Coffee,
            'S' => MachineMode::SteamS,
            'V' => MachineMode::SteamV,
            'C' => MachineMode::SteamC,
            'X' => MachineMode::Offline,
            other => MachineMode::Unknown(other),
        }
    }
}

#[derive(Debug, Default, Clone, PartialEq, Eq)]
pub struct TelemetryFrame {
    pub raw_string: String,
    pub mode: MachineMode,
    pub sw_version: String,           // e.g. "1.10"
    pub boiler_now_c: u16,            // e.g. 37
    pub boiler_target_c: Option<u16>, // Some(138) or None if Lxx
    pub no_water_code: Option<u16>,   // Some(65) if "L65"
    pub hx_now_c: u16,                // e.g. 35
    pub boost_countdown_s: u16,       // e.g. 0000 -> 0
    pub heating_on: bool,             // "1"/"0"
    pub pump_on: bool,                // "1"/"0"
}

impl TelemetryFrame {
    pub fn offline_frame() -> Self {
        Self {
            raw_string: "offline".to_string(),
            mode: MachineMode::Offline,
            ..Self::default()
        }
    }

    pub fn debug_frame() -> Self {
        Self {
            raw_string: "C1.10,122,128,092,0000,1,0".to_string(),
            mode: MachineMode::SteamC,
            sw_version: "1.10".to_string(),
            boiler_now_c: 122,
            boiler_target_c: Some(128),
            hx_now_c: 92,
            boost_countdown_s: 0,
            heating_on: true,
            pump_on: false,
            no_water_code: None,
        }
    }

    pub fn debug_pump_on_frame() -> Self {
        Self {
            raw_string: "C1.10,120,138,090,0000,1,1".to_string(),
            mode: MachineMode::SteamC,
            sw_version: "1.10".to_string(),
            boiler_now_c: 120,
            boiler_target_c: Some(138),
            hx_now_c: 90,
            boost_countdown_s: 0,
            heating_on: true,
            pump_on: true,
            no_water_code: None,
        }
    }

    pub fn debug_no_water_frame() -> Self {
        Self {
            raw_string: "C1.10,122,L65,085,0000,0,0".to_string(),
            mode: MachineMode::Coffee,
            sw_version: "1.10".to_string(),
            boiler_now_c: 122,
            boiler_target_c: None,
            hx_now_c: 85,
            boost_countdown_s: 0,
            heating_on: false,
            pump_on: false,
            no_water_code: Some(65),
        }
    }
}

#[derive(Debug, Clone, PartialEq, Eq)]
pub enum ParseError {
    Empty,
    BadPrefix,
    WrongFieldCount { got: usize, expected: usize },
    BadNumber { field: &'static str, value: String },
    BadBool { field: &'static str, value: String },
}

/// Parses UART line format:
/// <Mode><Version>,<boiler_now>,<boiler_target_or_Lxx>,<hx_now>,<boost>,<heating>,<pump>
/// Examples:
/// - C1.10,037,138,035,0000,0,1
/// - C1.10,037,L65,035,0000,0,0   (no water)
/// - +1.10,089,P75,067,0000,0,0   (P-prefix seen at cold startup in xmode_coffee; semantics TBD)
pub fn parse_uart_line(line: &str) -> Result<TelemetryFrame, ParseError> {
    let s = line.trim();
    if s.is_empty() {
        return Err(ParseError::Empty);
    }

    // First char is the machine mode
    let mut chars = s.chars();
    let mode_char = chars.next().ok_or(ParseError::Empty)?;
    let mode = MachineMode::from_char(mode_char);

    // Until the first comma is a software version (e.g. "1.10")
    let rest = &s[mode_char.len_utf8()..];
    let comma_pos = rest.find(',').ok_or(ParseError::BadPrefix)?;
    let sw_version = rest[..comma_pos].to_string();

    let after = &rest[comma_pos + 1..];
    let parts: Vec<&str> = after.split(',').collect();

    // Expected 6 fields after version:
    // boiler_now, boiler_target_or_Lxx, hx_now, boost, heating, pump
    if parts.len() != 6 {
        return Err(ParseError::WrongFieldCount {
            got: parts.len(),
            expected: 6,
        });
    }

    let boiler_now_c = parse_u16(parts[0], "boiler_now_c")?;

    let (boiler_target_c, no_water_code) = {
        let t = parts[1].trim();
        if let Some(code) = t.strip_prefix('L') {
            let code = parse_u16(code, "no_water_code")?;
            (None, Some(code))
        } else if t.starts_with(|c: char| c.is_ascii_alphabetic()) {
            // Non-numeric prefix other than 'L' — observed as "Pxx" at cold startup in xmode_coffee.
            // Exact semantics are still under investigation (possibly power-up / initial-heating phase).
            // Accepted without error; boiler_target treated as unknown until the frame normalises.
            (None, None)
        } else {
            let target = parse_u16(t, "boiler_target_c")?;
            (Some(target), None)
        }
    };

    let hx_now_c = parse_u16(parts[2], "hx_now_c")?;
    let boost_countdown_s = parse_u16(parts[3], "boost_countdown_s")?;
    let heating_on = parse_bool01(parts[4], "heating_on")?;
    let pump_on = parse_bool01(parts[5], "pump_on")?;

    let raw_string = line.to_string();

    Ok(TelemetryFrame {
        raw_string,
        mode,
        sw_version,
        boiler_now_c,
        boiler_target_c,
        no_water_code,
        hx_now_c,
        boost_countdown_s,
        heating_on,
        pump_on,
    })
}

fn parse_u16(s: &str, field: &'static str) -> Result<u16, ParseError> {
    let t = s.trim();
    t.parse::<u16>().map_err(|_| ParseError::BadNumber {
        field,
        value: t.to_string(),
    })
}

fn parse_bool01(s: &str, field: &'static str) -> Result<bool, ParseError> {
    match s.trim() {
        "0" => Ok(false),
        "1" => Ok(true),
        other => Err(ParseError::BadBool {
            field,
            value: other.to_string(),
        }),
    }
}

const MIN_SHOT_SECS: u64 = 15;
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

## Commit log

2026-08-28 feat(scale): add dual-HX711 load-cell scale with calibration wizard
    Adds hardware-agnostic calibration math + NVS persistence (scale.rs),
    a bit-banged HX711 driver (hx711.rs), a CalibrationWizard screen
    triggered by holding Button1 for 3s, and a live weight readout on the
    Dashboard that auto-tares the moment a shot starts.
    Claude-Session: https://claude.ai/code/session_011yGqamJeWCJ1JAwKL9S712
2026-08-28 feat(scale): independent SCK pins per HX711, hardware docs, and a scale-test bring-up variant
    - hx711.rs/setup.rs: each HX711 now gets its own SCK line (left: GPIO26,
    right: GPIO27) instead of sharing one clock pin.
    - docs/hardware.md: document the corrected dual-HX711 wiring, add a
    DevKitV1 D<n> silkscreen column, and a complete pin-mapping table.
    - New optional `scale-test` cargo feature for hardware bring-up with
    only the display + scale wired (no Lelit Mara UART connection): shows
    raw, uncalibrated, EMA-smoothed left/right/sum ADC counts in the
    Weight field instead of the normal calibrated net weight.
    - scale.rs: adds RawSignalSmoother (exponential moving average) used by
    the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
    [fsm.rs, global_state.rs, hx711.rs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]
2026-09-12 feat(dashboard,scale): boot text, gauge-by-weight, and scale reading fixes
    Dashboard/connecting screen:
    - Timer/Weight stack: swap centered_half_height for centered_fixed_height
    so the BigText glyph gets its full needed rows instead of being clipped
    by a second, redundant halving on top of the vertical Timer/Weight split
    - Weight gains a decimal (German comma, not period — the period glyph is
    too small to render at this size) and a 2px upward nudge
    - Shot gauge ("%") now tracks extracted weight (40g = 100%) instead of
    elapsed time
    - Boot screen title: "MARA/TUI" -> "MAXI/TUI"
    - Regenerated rat_barista.png/.raw from a new source photo (handle visible)
    Scale (src/scale.rs, src/setup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
    [scale.rs, setup.rs]
2026-09-12 docs: correct stale scale/button/asset documentation
    - CLAUDE.md: Screens section described a nonexistent Button2 and a "Main"
    screen in the rotation — the crate has one physical button and a
    three-variant Screen enum (Dashboard/Graphs/Debug); the loading screen
    isn't a Screen variant at all. Fixed to match src/screens/screen.rs and
    src/setup.rs.
    - CLAUDE.md: asset regen example used the wrong dimensions (180x180,
    should be 180x240 to match the actual assets).
    - CLAUDE.md: documented the scale-test feature (was missing from the
    feature list entirely) and expanded the Scale section to cover the
    rolling trimmed-mean filter, the ASSUMED_CALIBRATION bring-up fallback,
    the weigh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
2026-09-12 feat(hardware): scale-integrated board revision, 3D-printed scale mount
    - Replace the board design (schematic, PCB, gerbers, .step) with the
    newer revision that includes the HX711 scale sockets — the previous
    files predated the scale feature entirely and no longer matched the
    firmware.
    - Add hardware/lib/footprints/maratui.pretty/HX711_Socket.kicad_mod.
    - Add hardware/3d-print/: printable case parts for the dual load-cell
    mount (doppelfuss = double foot, auflage_v2 = scale platform) as
    STEP/STL plus pre-sliced G-code.
    - hardware/README.md: HX711 wiring table, 3s-hold calibration note, and
    a 3D-Printed Parts section; drop the stale gerbers/maratui-v1.zip
    reference in favor of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
    [ImageToStl.com_auflage_v2.stl, ImageToStl.com_doppelfuss.stl, auflage_v2.stp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]
2026-09-12 chore(hardware): remove outdated PCB renders
    renders/front.png and renders/back.png predate the scale-integrated
    board revision and no longer match it. Drop the folder and its README
    section rather than leave stale images; re-render for the current
    revision when needed.
    Claude-Session: https://claude.ai/code/session_01Ko6obK5yneSFLNZKCRo7FE
2026-09-12 chore(hardware): add current PCB render
    Single render for the scale-integrated board revision, replacing the
    removed pre-scale front/back pair.
    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
2026-09-12 refactor(scale): remove ASSUMED_CALIBRATION bring-up fallback
    Both cells are now confirmed working and calibrated via the real wizard
    (persisted to NVS), so the temporary bring-up fallback — used to verify
    wiring before any calibration existed — is no longer needed.
    load_calibration() reverts to the original behavior: uncalibrated
    default (scale=0.0, rejected outright by ScaleReadingFilter) until the
    wizard has been run. Verified on real hardware: boots cleanly and picks
    up the stored NVS calibration with no fallback log line.
    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
    [setup.rs]
2026-09-13 feat(button): zero the scale on a fast double press
    Adds ButtonPressType::Double to the existing button-press classifier:
    two Short presses released within 400ms of each other are now
    reclassified as a single Double press instead of two Shorts.
    Double press zeroes the scale (AppStateMachine::tare_scale, shared
    with the existing shot-start auto-tare) regardless of the current
    screen or backlight state, and is ignored while the calibration
    wizard is active. The simulator exposes it via the Z key.
    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
    [fsm.rs]
2026-09-13 hardware: update PCB and gerbers for the ordered board revision
    Updated schematic/PCB and regenerated gerbers.zip for the board
    revision that was ordered from fab. Removed the now-superseded
    separate scale add-on gerber zip (260903_Platine_waage.zip) — the
    scale cells are part of the single-board gerbers.zip export.
    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
    [maratui-B_Cu.gbr, maratui-B_Mask.gbr, maratui-B_Silkscreen.gbr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]
2026-09-13 fix(button): defer lone Short dispatch so it can't collide with Double
    A Short press was fired immediately on release, before it was known
    whether a second Short would follow within the double-press window.
    That meant the first half of every double press (meant to zero the
    scale) also fired as a screen-toggling Short — e.g. Dashboard would
    flip to Graphs right before the scale got zeroed.
    ButtonState::update now holds a lone Short back instead of dispatching
    it; a new ButtonState::poll, called every main-loop tick regardless of
    press state, fires it once the double-press window elapses with no
    pairing second press. A press that does pair still fires the Double
    immediately from update(). T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
    [setup.rs]
2026-09-13 docs(hardware): add finished-build photos to the Scale section
    Three photos from the running installation: the scale mount fitted
    into the Mara X's drip tray, the mount itself with both HX711 cells
    wired, and the Dashboard showing a live weight reading.
    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
2026-09-13 docs: add finished-build photo gallery to the README's Scale section
    Same three photos already added to docs/hardware.md, surfaced in the
    top-level README too: the scale mount installed in the drip tray, the
    3D-printed mount with both HX711 cells wired, and the Dashboard
    showing a live weight reading.
    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
2026-09-18 feat(hardware): rework schematic/PCB and reorganize KiCad library
    Consolidates the ESP32, HX711 and TFT footprints/symbols/3D models into
    a single hardware/lib/ tree (3dshapes, footprints.pretty, symbols),
    replacing the old per-part library layout. Adds a BOM export (maratui.csv).
    [maratui.csv, maratui.kicad_pcb, maratui.kicad_sch]
2026-09-18 hardware: regenerate gerbers for the reworked board
    Replaces gerbers.zip with Mara_waage.zip as the manufacturing bundle
    and adds the paste-mask layers. Note: the new zip has no drill files
    (the old maratui-NPTH.drl/PTH.drl are dropped, not replaced) - check
    this before ordering the board.
    [maratui-B_Cu.gbr, maratui-B_Mask.gbr, maratui-B_Paste.gbr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]
2026-09-18 feat(hardware): add PCB assembly and enclosure STEP models
    Replaces maratui.step with Plarine_cps.step as the full board assembly
    export, and adds the 3D-printed enclosure lid/body (geh_deckel/geh_koerper)
    as STEP models. STL exports for the printer still need to be generated
    from these two.
    [00000000000_-_geh_deckel.stp, 00000000000_-_geh_koerper.stp, maratui.step]
2026-09-19 hardware: add missing drill files to the gerber export
    Generates maratui-NPTH.drl/PTH.drl with kicad-cli (excellon, metric,
    absolute origin, separate PTH/NPTH - matching the previous export
    convention) and adds them to Mara_waage.zip alongside the copper/mask/
    silkscreen layers, so the manufacturing bundle is complete again.
    [maratui-NPTH.drl, maratui-PTH.drl]
2026-09-27 fix(scale): shrink trimmed-mean window to cut multi-second weight lag
    Live hardware testing (timestamped serial logging while placing/removing
    weight and pulling a shot) showed a ~4s settling time after every real
    weight change, exactly matching the old 32-sample window at the observed
    ~130ms per-channel HX711 sample interval. Steady-state noise measured only
    ±1-2 raw counts, far less than the window was buying. Cutting the window
    to 8 samples settles in ~1s (verified live) with no loss of stability.
    [scale.rs]
2026-09-27 feat: publish scale weight over MQTT and add a Node-RED web dashboard
    Firmware:
    - Publish the displayed (tared) scale weight to `<prefix>/scale` as
    `{"weight_g": 36.2}`, only when it changes and at most every 250 ms, so
    sub-gram noise can't flood the outbound MQTT queue. A change inside the
    interval is not lost: the next sample after it publishes the latest value.
    - Add `weight_g` (shot yield, tared at shot start; null without a scale)
    to the `shot_ended` and `shot_aborted` events.
    - Grams are formatted from decigrams with integer math (exact, no float
    rounding).
    Dashboard (`dashboard/`):
    - `index.html`: dependency-free live page (temperatures with 10/30/60 min
    history, heating/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
    [fsm.rs, global_state.rs]
2026-09-27 fix(dashboard): keep short shots visible instead of dropping the curve
    The firmware reports any pump run under 15 s (`MIN_SHOT_SECS`) as
    `shot_aborted`. The page hid aborted runs entirely, so a real 13 s pour
    (46 g) showed its curve while running and then vanished when it ended.
    - Shot list: also keep short runs when >= 5 g landed in the cup, marked
    "kurz"; plain rinses stay out.
    - Shot chart: show the running pump run while it lasts, afterwards the
    newest listed shot, so a later rinse doesn't replace the last real shot.
    - Never place the end-of-shot point before the last sample (`duration` is
    whole seconds), which made the curve kink backwards.
    - docs: `shot_aborted` threshold is 15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
2026-09-27 fix(dashboard): keep the latest pump run's curve up until the next one starts
    Show the most recent run (running or finished, short or not) instead of
    falling back to the newest listed shot, per user request.
2026-09-27 feat(dashboard): persist the last 10 shots, archive older ones, HX behind shot curve
    - Shots survive Node-RED restarts and Pi power-off: the state function
    node writes the last 10 shots (with weight and HX curves) to
    $HOME/maratui/shots.json (write + fsync + rename) and reloads them in
    its On Start code, merging with any surviving in-memory state.
    - Shots pushed out of the last 10 are appended to
    $HOME/maratui/shotdoku.txt as a readable line (time, duration, weight,
    flow, HX range, short marker) plus weight per second.
    - Record HX temperature during each shot and draw it behind the weight
    curve on its own right-hand °C axis; older shots fall back to the
    temperature history.
    -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
2026-09-27 feat(dashboard): count cups in Node-RED and publish mara/cup_counter
    The firmware only displays `mara/cup_counter`; counting was left to a
    Home Assistant automation. Without HA nothing ever published the topic,
    so the total never changed.
    The state function node now counts every shot that enters the shot list,
    persists the total in $HOME/maratui/cups.json, and publishes it retained
    to mara/cup_counter (new mqtt out node), which updates the page and the
    ESP32 display. A value published from outside is adopted as the new
    count. On start the saved count is republished so the broker has it
    again after a Pi restart.
2026-09-27 feat(dashboard): save every shot's curve as a JPEG on the Pi
    - render_shot.py (Pillow): 1200x700 chart with the weight curve, HX
    temperature behind it on a right-hand °C axis, and date, duration,
    weight, flow and HX range in the title.
    - The state function writes the script to $HOME/maratui/ on start and
    renders $HOME/maratui/shots/<date>_<time>.jpg after every shot that
    enters the shot list (child_process, async, errors only logged).
    - On start, missing JPEGs are rendered for saved shots; shots recorded
    before per-shot HX existed get HX from the temperature history.
    Verified locally and on the Pi (JPEGs rendered for both existing shots).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
2026-10-02 feat(hardware): add Creo source data for the display enclosure
    Adds the native PTC Creo dataset (enclosure shells, skeleton, and the
    imported board assembly with ESP32 DevKit, 2.8" display and both HX711
    modules) as a single zip under hardware/creo/, and documents it in the
    hardware README together with the previously undocumented enclosure
    STEP exports and Plarine_cps.step.
2026-10-02 fix(hardware): correct HX711 silkscreen pin labels and regenerate gerbers
    The HX711 module footprint labelled its pins GND/SCK/DAT/3.3V in the
    reverse order of the actual pads (pad 7 = 3.3V ... pad 10 = GND), which
    led to the modules being soldered in reversed and shorting 3V3 to GND.
    The footprint now reads V3.3/CLK/DAT/GND next to pads 7/8/9/10 and the
    board copies of U2/U3 are updated from the library. Nets and routing of
    the HX711 pads are unchanged.
    Gerbers and drill files are regenerated from the current board (the
    previous export predated later layout edits), Mara_waage.zip is rebuilt
    from them, and the README now points at the archive that actually exists.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
    [maratui-B_Cu.gbr, maratui-B_Mask.gbr, maratui-B_Paste.gbr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]
2026-10-24 hardware(3d-print): update printed parts to latest revisions
    Enclosure body/lid v3, double foot v2, platform v2 (renamed), new
    stand angle bracket and strut STLs. Drop old v1 enclosure STEPs and
    the stale CR-10S G-code; update the README parts table.
2026-10-24 hardware(3d-print): add assembly STEP, stand sources and renders
    maratui_baugruppe.step combines the scale (double foot, 2 simplified
    load cells, 2 platforms) and the display enclosure on its stand.
    Positions come from the part geometry (strut slot, lid tabs, 15 mm
    load-cell hole spacing); assemble.py regenerates it and checks for
    collisions, render.py produces the four README renders.
2026-10-25 hardware: remove outdated Creo source archive
    The zip held the 2026-10-02 state (enclosure v1) and lacked the current
    parts (enclosure v3, double foot v2, stand bracket, strut). The STEP
    exports in 3d-print/ are the reference from now on.
2026-11-07 Dashboard: draw Timer, Weight and HX readouts with smooth digits
    Ratatui leaves the readout areas blank; DashboardDigits draws them right
    after terminal.draw via the new MaraUiApp::render_overlay, repainting in
    full only after a clear or a screen switch. The HX temperature is colored
    by zone: red heating up, green 88-95 C, orange above, gray offline.
2026-11-07 Dashboard: nudge Timer and Weight digits down
    The large glyph boxes reserve space below the digits for the comma's
    descender, so centered digits sat high. SmoothField gains a per-field
    vertical nudge with row clipping to the field.
2026-11-07 Smooth start screen title; move Timer digits lower
    - Start screen: "MAXI / TUI" drawn with anti-aliased JetBrains Mono letters
    (new TITLE_LETTERS glyph set) instead of BigText blocks.
    - Timer: the post-shot assessment label moves into the block's bottom
    border, so the digits use the whole inside and sit 18 px lower.
    - draw() records the rendered board so render_overlay always matches the
    frame; the overlay also runs after the boot-stage draws.
    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
2026-11-07 Button: short press zeroes the scale, double press switches screens
    Swaps the two gestures: zeroing is the frequent action, so it gets the
    single press. Double press now toggles Dashboard/Graphs (and the backlight
    during loading). Simulator keys keep their functions; docs updated.
2026-11-07 Weight: reserve a sign slot so a minus doesn't shift the digits
    SmoothField::with_sign_slot lays unsigned numbers out with a blank
    minus-wide cell in front, so crossing zero only adds or removes the minus.
    Numbers too wide for the field with the slot (100+ g) go without it.
2026-11-07 UI: new color palette for Dashboard and start screen
    Named palette constants replace the ANSI colors: dark gray frames with
    warm-white titles, cream header, amber indicators, blue HX value, white
    timer (no phase colors), muted green ready states, hidden empty bar
    segments, copper start screen title and progress bar.
2026-11-07 hardware: save KiCad project settings from current KiCad version
    KiCad rewrote the project file on open: explicit teardrop td_enabled
    flags, the new same_local_global_power ERC rule, empty net color maps and
    a re-sorted used_designators list. No design change.
2026-11-07 Add pixel-art boot animation to the start screen
    Replace the rat barista image and the "MAXI / TUI" title with a looping
    ten-second scene: a Mara X overheats and explodes, a red sports car pulls
    up, its driver gets out and waves, and they drive off. It plays until the
    first telemetry frame switches to the Dashboard.
    - Painted at half resolution into a 160x84 RGB565 canvas and streamed
    pixel-doubled; only rows that changed since the last frame are sent.
    - Frames are paced inside BootAnimation::render, called from
    render_overlay every loop tick.
    - Wi-Fi and MQTT bring-up run on a scoped worker thread so the
    animation keeps playing during boot.
    - Drop render_image, assets/rat_barista.raw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
2026-11-07 Tune dashboard palette to muted tones
    Colors picked with the local color editor: muted blue indicators, warm
    off-white timer/weight digits, sage HX zones, olive/green boiler gauge
    and a slate no-water warning.
2026-11-07 Add hardware-agnostic water tank tracker
    WaterTank books every pump run off a 2300 ml tank once it is over:
    pump only at 5 ml/s, a shot weighed on the scale once the cup weight
    settled (1 g = 1 ml plus a 25 ml correction for water that never reaches
    the cup), or a shot without scale estimated at 1 ml/s and flagged as
    estimated. With the scale, a run counts as a shot from 3 g in the cup;
    without, from 15 s of pumping. Warns at 500 ml or less, and reports the
    level to persist only after a reset or a 10 ml change.
    Pure millisecond-in, millilitre-out logic with host unit tests.
2026-11-07 Track tank water per pump run, confirm refills, persist to NVS
    - Book every pump run off GlobalAppState::water: pump start/stop from
    ShotStarted/ShotEnded/ShotAborted, cup weight from WeightUpdated while
    it settles, the scale counting as available while readings arrived
    within the last 2 s. tick() books runs whose weight never settles.
    - The machine's own no-water report sets the tank to 0 ml.
    - A short press confirms the refill (tank back to 2300 ml) only while
    the low-water warning shows on the Dashboard; otherwise it still zeroes
    the scale. On a dark screen it just wakes the backlight.
    - Restore the level from NVS ("water" namespace) at boot and save it
    after a refill/empty re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
2026-11-07 Dashboard: show remaining tank water and a refill popup
    - Banner: cup counter shortened to "N cups", followed by the remaining
    water as smooth digits ("1,85L", new WATER_DIGITS glyph set) and a
    four-cell tank bar; both turn orange-red at 500 ml or less.
    - Low water: a popup over the Timer/Weight column asks "Wasser
    nachgefüllt? Taste kurz drücken". It never shows during a shot nor in
    the 30 s after one, so it can't hide a running or just-finished shot;
    the banner stays red meanwhile. Its dark red background makes Ratatui
    repaint every covered cell, and the smooth Timer/Weight digits are
    skipped while it shows and repainted in full once it's gone.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
2026-11-08 Publish water tank bookings to <prefix>/water
    Every booked pump run, NVS save, refill, empty report and boot restore is
    published as JSON with the remaining level, so the web dashboard can show
    the tank and its log.
2026-11-08 Boot animation: alien abduction instead of the exploding Mara X
    The driver arrives in the red sports car and waves, a saucer with a
    rainbow flag and a boa-wearing alien beams her up, and the saucer explodes
    in the sky. The loop now fades from and to black so it restarts cleanly.
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2026-11-08 Preview the boot animation on the host without flashing
    examples/boot_frames.rs renders one loop with the firmware's own scene code
    into a file of RGB888 frames.
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
